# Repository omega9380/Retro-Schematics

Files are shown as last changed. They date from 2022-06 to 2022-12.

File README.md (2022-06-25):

# Retro Schematics
 Recreating retro computer schematics in KiCAD

I'm an IT administrator that likes to play around in KiCAD.  Needing a new project to keep me busy during downtime at work, I have decided to try my hand at recreating classic computer schematics.

Most retro schematics I have seen are scans from original system manuals.  While there are other folks that have recreated those schematics in various schematic CAD softwares like Eagle, Altium, or KiCAD, this is just fun for me.  It allows me to get to know KiCAD and all of its quirks and with this project I'll be able to help out the retro community.

My goal is to recreate the computer schematics as closely as the original diagrams that I find. I just think it will be helpful for all the retro folks out there to have an easy to reference schematic with some interactivity in a free-to-use software.

I will come straight to the point and say I suck at board design, but have become pretty good at symbol and schematic creation in KiCAD.  The goal of this repo is to provide the commuity a one-stop shop for schmatics for fixing thier old retro PCs.  And anyone can clone the repos and use the schematics to make thier own board designs (ATX format Commodore 64, anyone), or use these parts libraries to create addons that help the whole community enjoy thier classic computers and peripherals.

PDF versions of all schematics will be placed under "PDF Schematics" for those who don't want to install KiCAD.  The KiCAD projects will be under thier folders, seperated by company and device.

Note please that I am one guy, doing this on my own time.  So please don't expect that "one stop shop" to be available tomorrow!

If you like what I'm doing and want to help out, please branch and add to the repo if you have the skill, time, and inclination!

And if you want to help me out more directly, you can buy me a root beer:  

Any questions, comments, praises, worship, threats, or random thoughts, please DM me on Discord, I'm OmegaPrime#3078.

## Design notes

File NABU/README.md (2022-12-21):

# NABU
These are the schematics for the NABU PC, a Z80 based 8-bit computer.  The NABU PC was created in 1983 and was used to connect to the NABU Network, a cable-TV based early precursor to the World Wide Web that was available in Ottowa, Canada from 1982 to 1985.

A large number of the NABU PCs were recently posted on Ebay and the NABU hardware has become quite popular in the retro computing community.

The source document for this schematic replica is the "NABU Consolidated Documentation v1.0a" PDF.  This is a document compiled by user starkscon on Github, containing all the documentation he was able to find while exploring is own NABU.

## Notes on the schematic
- For whatever reason, the original schematic contains no part designators for any passives.  The only designators are for the ICs and I will label them thusly in the schematic.

## Links
- Check out starkscon on Github - [https://github.com/starkscon/nabu-z80](https://github.com/starkscon/nabu-z80)
- Adrian's Digital Basement video exploring the NABU - [https://www.youtube.com/watch?v=HLYjZoShjy0](https://www.youtube.com/watch?v=HLYjZoShjy0)

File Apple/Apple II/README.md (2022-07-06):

# Apple II

Source is the book *The Apple II Circuit Description* by Winston Gayler.

The schematics are in sections as opposed to a monolithic single schematic, so this looks like where we partake of the KiCAD heirarchal schematic system.

Hope you find this useful!

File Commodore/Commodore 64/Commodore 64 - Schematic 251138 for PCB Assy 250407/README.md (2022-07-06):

# Commodore 64

As we all know, there are multiple revisions of the C64 schematics.  My original plan was a top sheet, with the various versions of the schematic as sub-sheets, utilizing KiCAD's hierarchal sheet managament.  I quickly realized that this wouldn't really work, and it would make the C64 section of the repo HUGE once I was done.  I have since decided to seperate each version into its own project, based on the C64 Board Identification table on Page 17 of the Mar 1992 Service Manual (314001-03).

I will do my best to specify as much information as I can to match a schematic to a specific board, but there are so many out there that I may miss something.  Please put an issue in GitHub to let me know if I missed anything!

Most of the images and documents under the Documents folder here were found on the [Zimmers website](http://www.zimmers.net/), or on [MyOldComputer.nl](https://myoldcomputer.nl).   Please follow the links to these sites for a much more comprehensive document repository for the Commodore 64!

## Note on the RF Modulator schematic:

Several components are unlabeled or have no value.  This is due to the poor quality scan of the schematic from the service manuals.  If anyone can fill in  the blanks, please open an issue and let me know!

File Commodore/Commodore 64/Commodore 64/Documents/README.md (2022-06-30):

# Commodore 64

As we all know, there are multiple revisions of the C64 schematics.  What I plan on doing is a "top sheet" in KiCAD, with the various revision schematics as sub sheets for this top sheet.  I will do my best to specify as much information as I can to match a schematic to a specific board, but there are so many out there that I may miss something.  Please put an issue in GitHub to let me know if I missed anything!

Most of the images and documents here were found on the [Zimmers website](http://www.zimmers.net/).  I have saved them to this Documents folder while I work on the schematic for the C64, but I will remove them when the schematic is complete.  Please follow the link to Zimmers to get these files in the future!

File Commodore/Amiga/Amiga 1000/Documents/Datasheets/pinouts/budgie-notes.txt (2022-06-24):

Budgie is a chip that serves as the main data path element in the 
A1200 system. It provides the interface between the 32-bit processor 
bus and the 32-bit chip memory bus, generates the RAS and CAS 
select signals from the RAS and CAS timing signals that Alice 
supports. It also provides a 16-bit bus buffer which can be used for 
either an expansion bus or in this case the PCMCIA port data buffer. It 
also includes some miscellaneous functions, notably processor clock 
generation and 28Mhz/Genlock clock multiplexing.
It is implemented as a CMOS ASIC in a 128 Pin SMT package.
AdvancedAmiga 1200 System   11
Internally, the data path element is similar to Bridgette or the bus 
buffer/bridge logic implemented on the A3000 system. Data can be 
routed to/from the 32-bit processor port to either half of the 32-bit chip 
memory bus. Data can be bridged from the low order half of the chip 
memory bus to the high order half to support 16-bit Amiga chip 
accesses. Data read from memory is latched to meet the processor 
data hold requirements. CAS select logic is used to prevent contention 
when bridging the two halves of the chip bus.

The spare 16-bit expansion port(used for PCMCIA duty in the A1200) 
provides a simple path to/from the 16-bit processor port. The direction 
is dependent on the X-NOR of R_W and _BGACK signals to support 
either expansion bus or several purpose buffer requirements.

The memory decoding takes the RAS and CAS timing signals 
provided by Alice and the multiplexed address bus and generates 
appropriate selection for 32-bit accesses. It also uses A1/A0 and 
SIZ1/SIZ0 on processor accesses to do the right decoding there.

It supports 2-banks of 32 bit memory with 9-bit addressing for a total of 
2M-bytes of chip memory. RAS selection is used for bank selection, 
CAS selection is used for byte write control and to avoid contention on 
bridged reads. Refrcsh is done with CAS before RAS and the logic 
must assert all RAS and CAS signals during refresh cycles.

The processor clock generation simply X-NORS the 7MHz and *CDAC 
clocks to generate a 14MHz processor clock. The 28MHz/Genlock 
clock multiplexor is a simple 2 input multiplexor. It has no connection 
with the rest of the logic and can be used for other functions if desired. 
The CCK/4 output is provided for the PAL color burst generation 
circuitry.

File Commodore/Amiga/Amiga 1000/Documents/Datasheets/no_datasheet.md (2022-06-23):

# Missing Datasheets:

|Chip|More Info  |
|--|--|
|U4C - 8361 AGNUS| [Wikipedia Page](https://en.wikipedia.org/wiki/MOS_Technology_Agnus) |
|U4E - 8364 PAULA| [amigawiki Page (German)](https://www.amigawiki.org/doku.php?id=de:parts:paula)

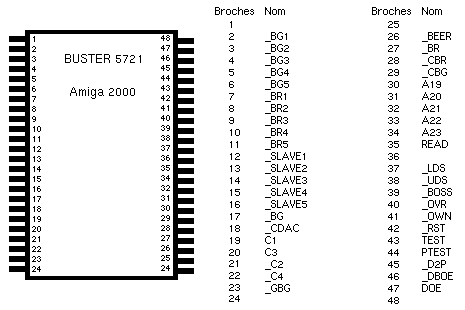
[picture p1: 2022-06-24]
Commodore/Amiga/Amiga 1000/Documents/Datasheets/pinouts/Buster.gif

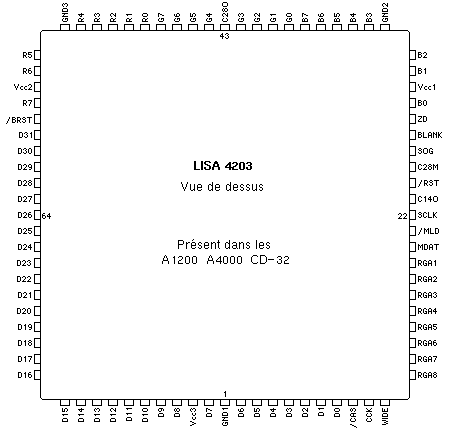
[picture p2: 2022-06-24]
Commodore/Amiga/Amiga 1000/Documents/Datasheets/pinouts/Lisa.gif

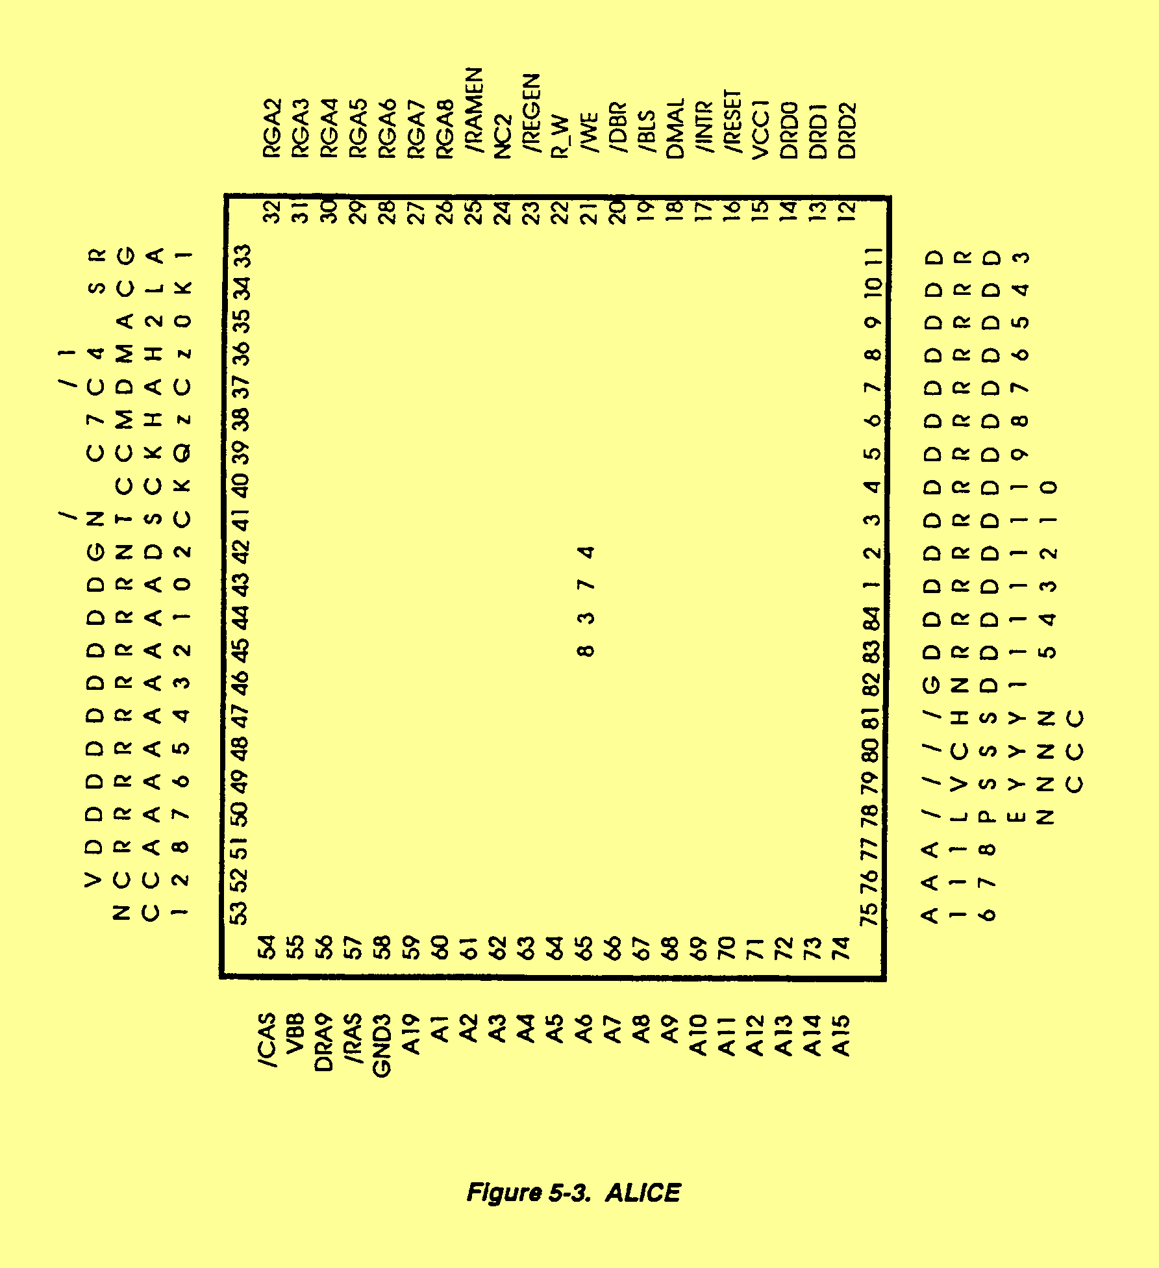
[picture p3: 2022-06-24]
Commodore/Amiga/Amiga 1000/Documents/Datasheets/pinouts/aa-alice.png

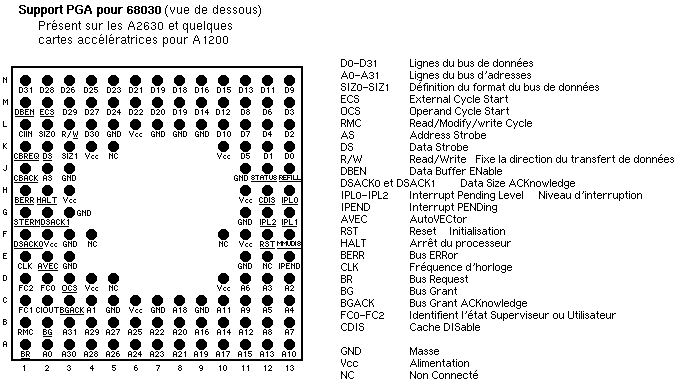
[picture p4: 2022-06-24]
Commodore/Amiga/Amiga 1000/Documents/Datasheets/pinouts/68030PGA.gif

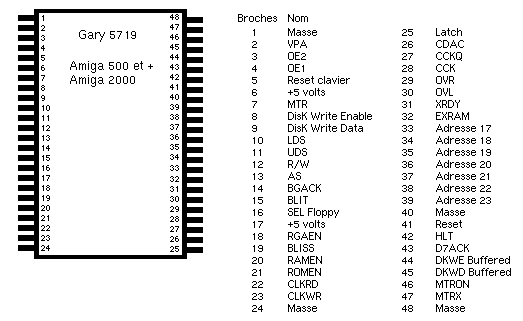
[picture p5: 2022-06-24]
Commodore/Amiga/Amiga 1000/Documents/Datasheets/pinouts/Gary.gif

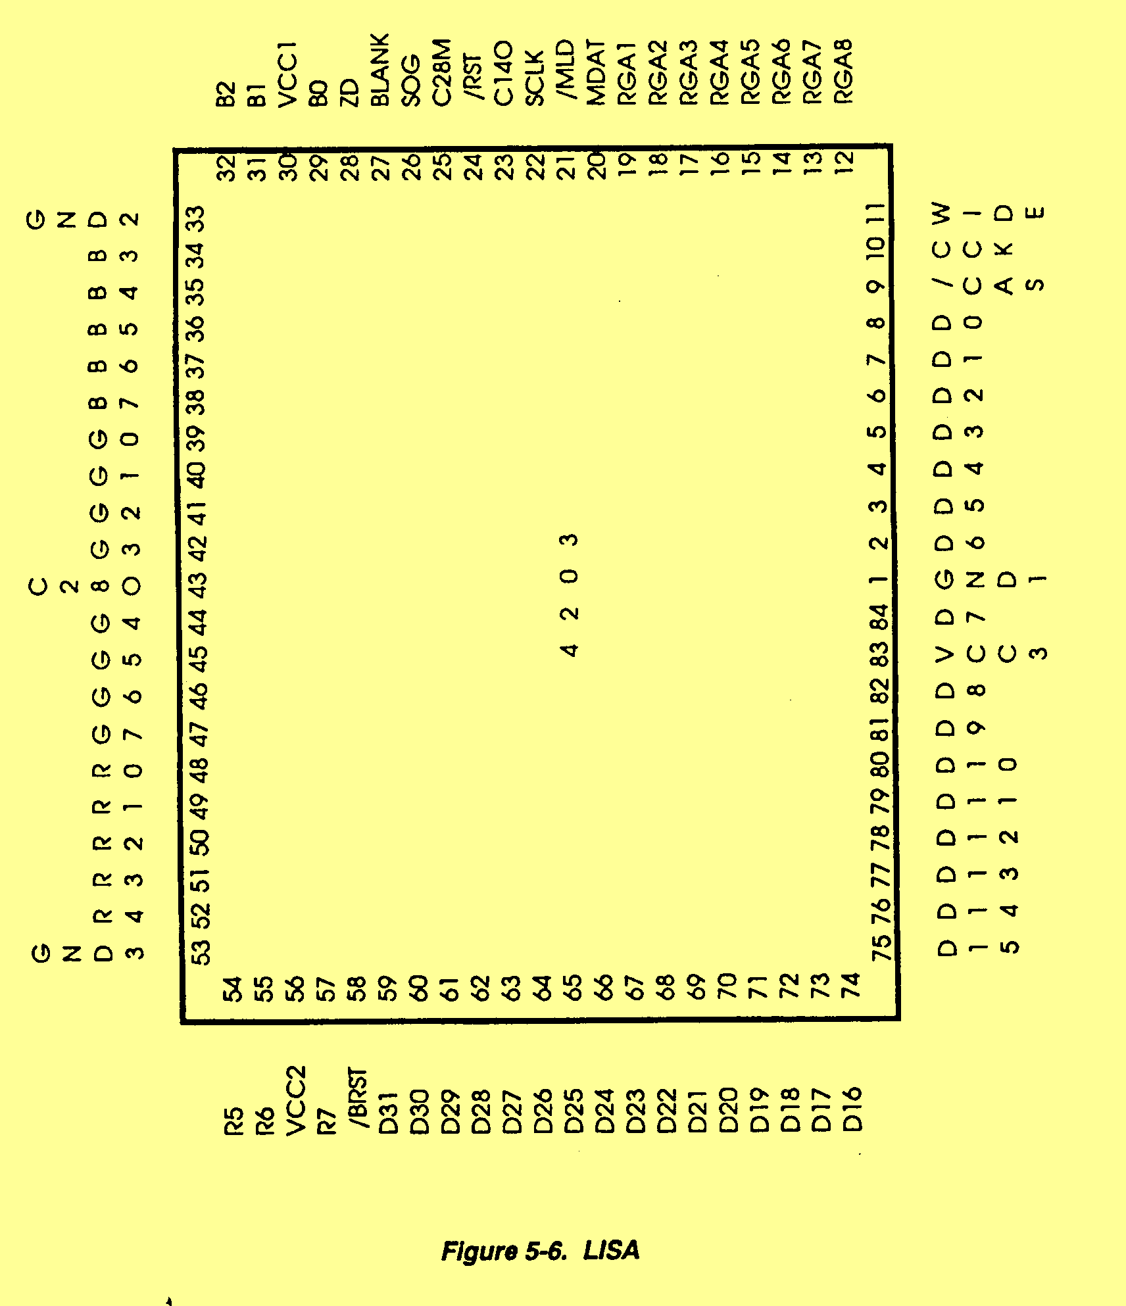
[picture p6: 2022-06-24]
Commodore/Amiga/Amiga 1000/Documents/Datasheets/pinouts/aa-lisa-plcc.png

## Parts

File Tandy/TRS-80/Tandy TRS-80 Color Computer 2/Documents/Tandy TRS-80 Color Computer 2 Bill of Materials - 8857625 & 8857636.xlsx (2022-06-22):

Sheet: Misc
ITEM | REF | DESCRIPTION | PART #
1 | 1 | PCB, MAIN LOGIC | 8709416
2 | 1 | LUG, FAST-ON | 8529016
3 | 9 | SOCKET, 16-PIN DIP (U1,14-21) | 8509003
4 | 3 | SOCKET, 20-PIN DIP (U3,5,6) | 8509009
5 | 2 | SOCKET, 24-PIN DIP (U12,13) | 8509001
6 | 5 | SOCKET, 40-PIN DIP (U2,7,8,22,23) | 8509002
7 | 1 | SWITCHCAP (RESET) | 8489066
8 | 1 | BRACKET, SWITCH (RESET) | 8729223
9 | 1 | HEATSINK, 6015-PBSE1 (Q1) | 8549016
10 | 2 | NUT, #6 KEPS | 8579004
11 | 1 | LABEL, PCB SERIAL | 8789963

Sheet: Capacitors (C)
REF | DESCRIPTION | PART #
C1 | 220µF, 16V, ELEC RAD | 8327221
C2 | 4700µF, 16V, ELEC RAD | 8328471
C3 | 0.1 µF, 50V, MONO AXIAL | 8374104
C4 | 0.1 µF, 50V, MONO AXIAL | 8374104
C5 | 100µF, 16V, ELEC RAD | 8327101
C6 | 0.1 µF, 50V, MONO AXIAL | 8374104
C7 | 0.02µF, 50V, CER DISK | 8303223
C8 | 0.02µF, 50V, CER DISK | 8303223
C9 | 0.02µF, 50V, CER DISK | 8303223
C10 | 0.02µF, 50V, CER DISK | 8303223
C11 | 100µF, 16V, ELEC RAD | 8327101
C12 | N.A.
C13 | 0.02µF, 50V, CER DISK | 8303223
C14 | 0.02µF, 50V, CER DISK | 8303223
C15 | 0.1 µF, 50V, MONO AXIAL | 8374104
C16 | 0.02µF, 50V, CER DISK | 8303223
C17 | 0.02µF, 50V, CER DISK | 8303223
C18 | 0.1 µF, 50V, MONO AXIAL | 8374104
C19 | 0.1 µF, 50V, MONO AXIAL | 8374104
C20 | 10µF, 25V, ELEC RD NP | 8396101
C21 | 0.1 µF, 50V, MONO AXIAL | 8374104
C22 | 0.02µF, 50V, CER DISK | 8303223
C23 | 0.02µF, 50V, CER DISK | 8303223
C24 | 0.1 µF, 50V, MONO AXIAL | 8374104
C25 | 0.1 µF, 50V, MONO AXIAL | 8374104
C26 | 0.001µF, 50V, POLY | 8352104
C27 | 0.02µF, 50V, CER DISK | 8303223
C28 | 0.1 µF, 50V, MONO AXIAL | 8374104
C29 | 0.1 µF, 50V, MONO AXIAL | 8374104
C30 | 0.1 µF, 50V, MONO AXIAL | 8374104
C31 | N.A.
C32 | 0.1 µF, 50V, MONO AXIAL | 8374104
C33 | 0.1 µF, 50V, MONO AXIAL | 8374104
C34 | 0.1 µF, 50V, MONO AXIAL | 8374104
C35 | 0.1 µF, 50V, MONO AXIAL | 8374104
C36 | 0.1 µF, 50V, MONO AXIAL | 8374104
C37 | 33pF, 50V, CER DISK | 8300334
C38 | 56pF, 50V, CER DISK | 8300564
C39 | 56pF, 50V, CER DISK | 8300564
C40 | 0.1 µF, 50V, MONO AXIAL | 8374104
C41 | N.A.
C42 | N.A.
C43 | 9-35pF TRIMMER | 8360356
C44 | 39pF, 50V, CER DISK | 8300394
C45 | 0.1 µF, 50V, MONO AXIAL | 8374104
C46 | 10µF, 25V, ELEC RAD | 8326102
C47 | 0.1 µF, 50V, MONO AXIAL | 8374104
C48 | 1µF, 50V, ELEC RAD | 8325104
C49 | N.A.
C50 | 0.1 µF, 50V, MONO AXIAL | 8374104
C51 | 0.1 µF, 50V, MONO AXIAL | 8374104
C52 | 0.1 µF, 50V, MONO AXIAL | 8374104
C53 | 0.1 µF, 50V, MONO AXIAL | 8374104
C54 | 0.1 µF, 50V, MONO AXIAL | 8374104
C55 | 0.1 µF, 50V, MONO AXIAL | 8374104
C56 | 0.1 µF, 50V, MONO AXIAL | 8374104
C57 | 0.1 µF, 50V, MONO AXIAL | 8374104
C58 | 0.1 µF, 50V, MONO AXIAL | 8374104
C59 | 150pF, 50V, CER DISK | 8301154
C60 | 33pF, 50V, CER DISK | 8300334
C61 | 150pF, 50V, CER DISK | 8301154
C62 | 10µF, 25V, ELEC RAD | 8326102

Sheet: Connectors (J)
REF | DESCRIPTION | PART #
J1 | 6-PIN DIN | 8519095
J2 | 6-PIN DIN | 8519095
J3 | 4-PIN DIN | 8519094
J4 | 5-PIN DIN | 8519085
J5 | KEYBOARD | 8519176
J6 | 40-PIN RIGHT ANGLE | 8519139

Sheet: Diodes (CR, FB, K)
REF | DESCRIPTION | PART #
CR1 | 1N4002, 50V, 1A | 8150002
CR2 | 1N4002, 50V, 1A | 8150002
CR3 | 1N5401, 100V, 3A | 8160401
CR4 | 1N5401, 100V, 3A | 8160401
CR5 | 1N4148 | 8150148
CR6 | 1N4148 | 8150148
CR7 | 1KF20-04 | 8160020
CR8 | 1KF20-04 | 8160020
CR9 | 1N4148 | 8150148
CR10 | 1N4148 | 8150148
CR11 | 1N4148 | 8150148
CR12 | 1N4148 | 8150148
CR13 | 1KF20-04 | 8160020
FB1 | FERRITE BEAD | 8419013
FB2 | FERRITE BEAD | 8419014
FB4 | FERRITE BEAD | 8419015
FB7 | FERRITE BEAD | 8419016
K1 | RELAY | 8429107

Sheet: Transistors (Q)
REF | DESCRIPTION | PART #
Q1 | SJ5812 | 8110569
Q2 | MPS3904 | 8110904

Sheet: Resistors (R, RP)
REF | DESCRIPTION | PART #
R1 | 51Ω, 1/4W 5% | 8207051
R2 | 0.1Ω, 1/2W 5% | 8247002
R3 | 270Ω, 1/4W 5% | 8207127
R4 | 510Ω, 1/4W 5% | 8207151
R5 | 4.7K, 1/4W 5% | 8207247
R6 | 4.7K, 1/4W 5% | 8207247
R7 | 10K, 1/4W 5% | 8207310
R8 | 10K, 1/4W 5% | 8207310
R9 | 1K, 1/4W 5% | 8207210
R10 | 9.1K, 1/4W 5% | 8207291
R11 | 100Ω, 1/2W 5% | 8217110
R12 | 4.7K, 1/4W 5% | 8207247
R13 | 10K, 1/4W 5% | 8207310
R14 | 4.7K, 1/4W 5% | 8207247
R15 | 1.5K, 1/4W 5% | 8207215
R16 | 10K, 1/4W 5% | 8207310
R17 | 4.7K, 1/4W 5% | 8207247
R18 | 4.7K, 1/4W 5% | 8207247
R19 | 100Ω, 1/4W 5% | 8207110
R20 | 100K, 1/4W 5% | 8207410
R21 | 4.7K, 1/4W 5% | 8207247
R22 | 100K, 1/4W 5% | 8207410
R23 | 220Ω, 1/2W 5% | 8217122
R24 | 100Ω, 1/4W 5% | 8207110
R25 | 150Ω, 1/4W 5% | 8207115
R26 | 100Ω, 1/4W 5% | 8207110
RP1 | RES PACK, 4.7K, 10 PIN | 8294247

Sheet: Switches (S)
REF | DESCRIPTION | PART #
S1 | DPDT, PUSH ON/OFF | 8489062
S2 | SPST, MOMENTARY | 8489065

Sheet: Integrated Circuits (U, Y)
REF | DESCRIPTION | PART #
U1 | CUSTOM SALT | 8050527
U2 | MC6821, PIA | 8040821
U3 | CUSTOM DAC | 8050526
U4 | NE555 | 8040055
U5 | 74LS273, OCTAL LATCH | 8020273
U6 | 74LS244, BUFFER | 8020244
U7 | MC6822, PIA | 8040822
U8 | MC6847, VDG | 8040847
U9 | RF MODULATOR | 8429500
U10 | 74LS02, QUAD NOR | 8020002
U11 | 74LS138, DECODER | 8020138
U12 | MC68A364, ROM | 8040364B
*U13 | MC68A364, ROM | 8040364A
U14 | MCM4517, RAM | 8040517
U15 | MCM4517, RAM | 8040517
U16 | MCM4517, RAM | 8040517
U17 | MCM4517, RAM | 8040517
U18 | MCM4517, RAM | 8040517
U19 | MCM4517, RAM | 8040517
U20 | MCM4517, RAM | 8040517
U21 | MCM4517, RAM | 8040517
U22 | MC6883, SAM | 8040278
U23 | MC6809E, CPU | 8040809
Y1 | CRYSTAL, 14.31818MHz | 8409008
* USED ON 8857636 EXTENDED BASIC PCB ONLY

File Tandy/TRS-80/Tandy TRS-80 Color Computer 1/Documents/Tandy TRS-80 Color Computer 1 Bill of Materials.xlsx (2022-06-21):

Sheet: Capacitors (C#)
SYMBOL | DESCRIPTION | MFG PART # | RS PART #
C1 | 1µF, 50V, electrolytic, radial | 8325104 | AAC105QJAP
C2 | 10µF, 25V, non-polarized, radial | 8396101 | AAC106QFBP
C3 | 100µF, 16V, electrolytic, radial | 8326251 | AAC107QDAP
C4 | 9 - 35 pF, variable | 8360356 | AC-4926
C5 | 100µF, 16V, electrolytic, radial | 8326251 | AAC107QDAP
C6 | 25µF, electrolytic, radial | 8326251 | AAC256MDAP
C7 | 1500µF, 35V, electrolytic, radial | 8318153 | AAC158QGAA
C8 | 100µF, 16V, electrolytic, radial | 8326251 | AAC107QDAP
C9 | 470µF, 35V, electrolytic, radial | 8327473 | AAC477QGAP
C10 | 10,000µF, 16V, electrolytic, axial | 8319101 | AAC109QDAA
C11 | 0.001µF, 50V, PO | 8352104 | AAC102KJGP
C12 | 100µF, 16V, electrolytic, radial | 8326251 | AAC107QDAP
C13 | 0.001µF, 50V, ceramic disc | 8302104 | AAC102QJCP
C14 | 220µF, 16V, electrolytic, radial | 8327221 | AAC227QDAP
C15 | 220µF, 16V, electrolytic, radial | 8327221 | AAC227QDAP
C16 | 220µF, 16V, electrolytic, radial | 8327221 | AAC227QDAP
C17 | 1µF, 50V, tantalum | 8335104 | AAC105QJTP
C18 | 1µF, 50V, tantalum | 8335104 | AAC105QJTP
C19 | 1µF, 50V, tantalum | 8335104 | AAC105QJTP
C20 | 0.01µF, 1KV, ceramic disc | 8303108 | AAC103QXCP
C21 | 0.01µF, 1KV, ceramic disc | 8303108 | AAC103QXCP
C22 | 0.01µF, 1KV, ceramic disc | 8303108 | AAC103QXCP
C23 | 0.1µF, 50V, monolithic,axial | 8374104 | AAC104QJCA
C24 | 0.1µF, 50V, monolithic,axial | 8374104 | AAC104QJCA
C25 | 0.1µF, 50V, monolithic,axial | 8374104 | AAC104QJCA
C26 | 0.022µF, 25V | 8303244 | AAC223QJCP
C27 | 0.1µF, 50V, monolithic,axial | 8374104 | AAC104QJCA
C28 | 0.1µF, 50V, monolithic,axial | 8374104 | AAC104QJCA
C29 | 0.1µF, 50V, monolithic,axial | 8374104 | AAC104QJCA
C30 | 0.022µF, 25V | 8303244 | AAC223QJCP
C31 | 0.1µF, 50V, monolithic,axial | 8374104 | AAC104QJCA
C32 | 0.1µF, 50V, monolithic,axial | 8374104 | AAC104QJCA
C33 | 0.1µF, 50V, monolithic,axial | 8374104 | AAC104QJCA
C34 | 0.1µF, 50V, monolithic,axial | 8374104 | AAC104QJCA
C35 | 0.1µF, 50V, monolithic,axial | 8374104 | AAC104QJCA
C36 | 0.1µF, 50V, monolithic,axial | 8374104 | AAC104QJCA
C37 | 0.1µF, 50V, monolithic,axial | 8374104 | AAC104QJCA
C38 | 0.1µF, 50V, monolithic,axial | 8374104 | AAC104QJCA
C39 | 0.1µF, 50V, monolithic,axial | 8374104 | AAC104QJCA
C40 | 0.1µF, 50V, monolithic,axial | 8374104 | AAC104QJCA
C41 | 0.1µF, 50V, monolithic,axial | 8374104 | AAC104QJCA
C42 | 0.1µF, 50V, monolithic,axial | 8374104 | AAC104QJCA
C43 | 0.1µF, 50V, monolithic,axial | 8374104 | AAC104QJCA
C44 | 0.1µF, 50V, monolithic,axial | 8374104 | AAC104QJCA
C45 | 0.1µF, 50V, monolithic,axial | 8374104 | AAC104QJCA
C46 | 0.1µF, 50V, monolithic,axial | 8374104 | AAC104QJCA
C47 | 0.1µF, 50V, monolithic,axial | 8374104 | AAC104QJCA
C48 | 0.1µF, 50V, monolithic,axial | 8374104 | AAC104QJCA
C49 | 0.1µF, 50V, monolithic,axial | 8374104 | AAC104QJCA
C50 | 0.1µF, 50V, monolithic,axial | 8374104 | AAC104QJCA
C51 | 39pF, ceramic disc | 8300394 | AAC390QJCP
C52 | 20pF, 50V, ceramic disc | 8300204 | AAC200QJCP
C53 | 56pF, 50V, ceramic disc | 8300564 | AAC560QJCP
C54 | 0.022µF, 25V | 8303244 | AAC223QJCP
C55 | 0.022µF, 25V | 8303244 | AAC223QJCP
C56 | 0.022µF, 25V | 8303244 | AAC223QJCP
C57 | 0.01µF, 50V, ceramic disc | 8303104 | AAC103QJCP
C58 | 0.01µF, 50V, ceramic disc | 8303104 | AAC103QJCP
C59 | 0.022µF, 25V | 8303244 | AAC223QJCP
C60 | 0.022µF, 25V | 8303244 | AAC223QJCP
C61 | 0.1µF, 50V, monolithic,axial | 8374104 | AAC104QJCA
C62 | 0.1µF, 50V, monolithic,axial | 8374104 | AAC104QJCA
C63 | 0.1µF, 50V, monolithic,axial | 8374104 | AAC104QJCA
C64 | 0.1µF, 50V, monolithic,axial | 8374104 | AAC104QJCA
C65 | 0.1µF, 50V, monolithic,axial | 8374104 | AAC104QJCA
C66 | 0.1µF, 50V, monolithic,axial | 8374104 | AAC104QJCA
C67 | 0.1µF, 50V, monolithic,axial | 8374104 | AAC104QJCA
C68 | 0.1µF, 50V, monolithic,axial | 8374104 | AAC104QJCA
C69 | 0.1µF, 50V, monolithic,axial | 8374104 | AAC104QJCA
C70 | 0.1µF, 50V, monolithic,axial | 8374104 | AAC104QJCA
C71 | 0.1µF, 50V, monolithic,axial | 8374104 | AAC104QJCA
C72 | 0.1µF, 50V, monolithic,axial | 8374104 | AAC104QJCA
C73 | 56pF, 50V, ceramic disc | 8300564 | AAC560QJCP
C74 | 0.022µF, 25V | 8303244 | AAC223QJCP
C75 | 56pF, 50V, ceramic disc | 8300564 | AAC560QJCP
C76 | 0.022µF, 25V | 8303244 | AAC223QJCP
C77 | 0.022µF, 25V | 8303244 | AAC223QJCP
C78 | 0.022µF, 25V | 8303244 | AAC223QJCP
C79 | 0.022µF, 25V | 8303244 | AAC223QJCP
C80 | 0.022µF, 25V | 8303244 | AAC223QJCP
C81 | 0.022µF, 25V | 8303244 | AAC223QJCP
C82 | 0.0022µF, 50V | 8302224 | AAC222MJCP
C83 | 0.001µF, 50V, ceramic disc | 8302104 | AAC102QJCP
C84 | 0.022µF, 25V | 8303244 | AAC223QJCP
C85 | 220pF, 50V, ceramic disc | 8301224 | AAC221QJCP

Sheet: Connectors (P#)
SYMBOL | DESCRIPTION | MFG PART # | RS PART #
P1 | 40 pin, AMP | 8519093 | AJ6902
P2 | 4 pin DIN | 8519094 | AJ6904
P3 | 6 pin DIN | 8519095 | AJ6905
P4 | 6 pin DIN | 8519095 | AJ6905
P5 | 5 pin DIN | 8519085 | AJ6903
*P6 | Keyboard shield connector | 8519104 | AJ6907
P7 | 16 pin Header | 8519106 | AJ6906
* will not appear on later revision Boards

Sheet: Crystals (X#)
SYMBOL | DESCRIPTION | MFG PART # | RS PART #
X1 | 14.31818MHz | 8409008 | AMX2797

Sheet: Diodes (CR#)
SYMBOL | DESCRIPTION | MFG PART # | RS PART #
CR1 | 1N4148 | 8150148 | ADX1152
CR2 | 1N4148 | 8150148 | ADX1152
CR3 | 1N4148 | 8150148 | ADX1152
CR4 | 1N4148 | 8150148 | ADX1152
CR5 | 1N4148 | 8150148 | ADX1152
CR6 | 1N4148 | 8150148 | ADX1152
CR7 | 1N4148 | 8150148 | ADX1152
CR8 | 1N4002 | 8150002 | ADX1148
CR9 | 1N982, zener | 8150982 | ADX1103
CR10 | 1N982, zener | 8150982 | ADX1103
CR11 | VM-28, bridge rectifier | 8160028 | AMX4582
CR12 | 1N5401, 100V, 3A | 8160401 | ADX1474
CR13 | 1N5401, 100V, 3A | 8160401 | ADX1474
CR14 | 1N4002 | 8150002 | ADX1148
CR15 | 1N4002 | 8150002 | ADX1148
CR16 | 1N5228, 3.9V, zener | 8150228 | ADX1473
CR17 | 1N4735, 6.2V, zener | 8150735 | ADX0214

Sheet: Fuses (F#)
SYMBOL | DESCRIPTION | MFG PART # | RS PART #
F1 | 700mA (0.7A) | 8479003 | AHF1185

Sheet: Inductors (L#)
SYMBOL | DESCRIPTION | MFG PART # | RS PART #
L1 | 3.3µh | 8419005 | ACA8059
L2 | 3.3µh | 8419005 | ACA8059
L3 | 3.3µh | 8419005 | ACA8059

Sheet: Integrated Circuits (U#)
SYMBOL | DESCRIPTION | MFG PART # | RS PART #
U1 | MC6809E, CPU | 8040809 | AXX3051
U2 | MC14050B, Latch | 8030050 | AMX4584
^U3 | MCM68A364, BASIC ROM | 8040364 | AXX3052
U4 | MC6821, PIA | 8040821 | AMX4578
U5 | UM1285-8, Modulator | 8050285 | AMX4576
U6 | 74LS273, Ocatal Flip-Flop | 8020273 | AMX4227
U7 | MC6847, VDG | 8040847 | AMX4575
U8 | MC6821, PIA | 8040821 | AMX4578
U9 | MC14529B, Data Separator | 8030529 | AMX4585
U10 | MC6883L, SAM | 8040278 | AMX4579
U11 | 74LS138, Decoder | 8020138 | AMX4583
U12 | MC1372, Video Mixer | 8020372 | AMX4574
U13 | 723C, +5V, Regulator | 8050723 | AMX3548
U14 | LM339, Quad Comparator | 8050339 | AMX4200
U15 | 741C, OpAmp | 8050741 | AMX4258
U16 | 74LS244, Buffer | 8020244 | AMX3864
U17 | 78M12, +12V, Regulator | 8050812 | AMX4577
U18 | 79M12, -12V, Regulator | 8050912 | AMX1488
U19 | 79L05, -5V Regulator | 8051905 | AMX4260
*U20 | MCM4027AC3, 4K RAM | 8040027 | AXX3044
*U21 | MCM4027AC3, 4K RAM | 8040027 | AXX3044
*U22 | MCM4027AC3, 4K RAM | 8040027 | AXX3044
*U23 | MCM4027AC3, 4K RAM | 8040027 | AXX3044
*U24 | MCM4027AC3, 4K RAM | 8040027 | AXX3044
*U25 | MCM4027AC3, 4K RAM | 8040027 | AXX3044
*U26 | MCM4027AC3, 4K RAM | 8040027 | AXX3044
*U27 | MCM4027AC3, 4K RAM | 8040027 | AXX3044
†U28 | MCM68A364, BASIC ROM Extended | 8042364 | AXX3054
U29 | 74LS02, Quad NOR Gate | 8020002 | AMX3551
^ Handwritten note: SCM90590C; 8040364A; Rev 1.18112.
* For 16K RAM Model
U20 - U27 | SCM90072C, 16K RAM | 8040016 | AXX3055
† For 16K RAM version only

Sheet: Relays (K#)
SYMBOL | DESCRIPTION | MFG PART # | RS PART #
K1 | R7336-1 | 8429102 | AR8130

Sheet: Resistors (R#)
SYMBOL | DESCRIPTION | MFG PART # | RS PART #
R1 | 100K, 1/4W, 5% | 8207410 | AN0371EEC
R2 | 100K, 1/4W, 5% | 8207410 | AN0371EEC
R3 | 4.7K, 1/4W, 5% | 8207247 | AN0247EEC
R4 | 4.7K, 1/4W, 5% | 8207247 | AN0247EEC
R5 | 4.7K, 1/4W, 5% | 8207247 | AN0247EEC
R6 | 4.7K, 1/4W, 5% | 8207247 | AN0247EEC
R7 | 4.7K, 1/4W, 5% | 8207247 | AN0247EEC
R8 | 18K, 1/4W, 5% | 8207318 | AN0303EEC
R9 | 150 ohm, 1/4W, 5% | 8207115 | AN0142EEC
R10 | 10K, 1/4W, 1% | 8201310 | AN0281BEE
R11 | 20K, 1/4W, 1% | 8201320 | AN0306BEE
R12 | 40.2K, 1/4W, 1% | 8201340 | AN0597BEE
R13 | 80.6K, 1/4W, 1% | 8201381 | AN0359BEE
R14 | 162K, 1/4W, 1% | 8201416 | AN0385BEE
R15 | 324K, 1/4W, 1% | 8201432 | AN0408BEE
R16 | 3.9K, 1/4W, 5% | 8207239 | AN0237EEC
R17 | 470 ohm, 1/4W, 5% | 8207147 | AN0169EEC
R18 | 750 ohm, 1/4W, 5% | 8207175 | AN0185EEC
R19 | 12K, 1/4W, 5% | 8207312 | AN0288EEC
R20 | 360 ohm, 1/4W, 5% | 8207136 | AN0159EEC
R21 | 500 ohm, Trim Pot | 8279150 | AP7156
R22 | 10K, 1/4W, 5% | 8207310 | AN0281EEC
R23 | 3.9K, 1/4W, 5% | 8207239 | AN0237EEC
R24 | 1.5K, 1/4W, 5% | 8207215 | AN0206EEC
R25 | 1K, 1/4W, 5% | 8207210 | AN0196EEC
R26 | 1K, 1/4W, 5% | 8207210 | AN0196EEC
R27 | 100 ohm, 1/2W, 5% | 8217110 | AN0132EFB
R28 | 10K, 1/4W, 5% | 8207310 | AN0281EEC
R29 | 10K, 1/4W, 5% | 8207310 | AN0281EEC
R30 | 1K, 1/4W, 5% | 8207210 | AN0196EEC
R31 | 4.7K, 1/4W, 5% | 8207247 | AN0247EEC
R32 | 4.7K, 1/4W, 5% | 8207247 | AN0247EEC
R33 | 220 ohm, 1/4W, 5% | 8207122 | AN0149EEC
R34 | 8.2K, 1/4W, 5% | 8207282 | AN0271EEC
R35 | 6.8K, 1/4W, 5% | 8207268 | AN0262EEC
R36 | 56K, 1/4W, 5% | 8207356 | AN0345EEC
R37 | 56K, 1/4W, 5% | 8207356 | AN0345EEC
R38 | 15K, 1/4W, 5% | 8207315 | AN0297EEC
R39 | 1.5M, 1/4W, 5% | 8207515 | AN0450EEC
R40 | 1K, 1/4W, 5% | 8207210 | AN0196EEC
R41 | 24K, 1/4W, 5% | 8207324 | AN0526EEC
R42 | 75K, 1/4W, 5% | 8207375 | AN0527EEC
R43 | 1.5K, 1/4W, 5% | 8207215 | AN0206EEC
R44 | 4.7K, 1/4W, 5% | 8207247 | AN0247EEC
R45 | 180 ohm, 1/4W, 5% | 8207118 | AN0144EEC
R46 | 470 ohm, 1/4W, 5% | 8207147 | AN0169EEC
R47 | 1.5K, 1/4W, 5% | 8207215 | AN0206EEC
R48 | 10K, 1/4W, 5% | 8207310 | AN0281EEC
R49 | 10M, 1/4W, 5% | 8207610 | AN0482EEC
R50 | 100 ohm, 1/2W, 5% | 8217110 | AN0132EFB
R51 | 10K, 1/4W, 5% | 8207310 | AN0281EEC
R52 | 10K, 1/4W, 5% | 8207311 | AN0281EEC
R53 | 15K, 1/4W, 5% | 8207315 | AN0297EEC
R54 | 15K, 1/4W, 5% | 8207315 | AN0297EEC
R55 | 10M, 1/4W, 5% | 8207610 | AN0482EEC
R56 | 10M, 1/4W, 5% | 8207610 | AN0482EEC
R57 | 1K, 1/4W, 5% | 8207210 | AN0196EEC
R58 | 470 ohm, 1/4W, 5% | 8207147 | AN0169EEC
R59 | 68 ohm, 1/4W, 5% | 8207068 | AN0111EEC
R60 | 1K, Trim Pot | 8279210 | AP0835
R61 | 1.2K, 1/4W, 5% | 8207212 | AN0199EEC
R62 | 3.3K, 1/4W, 5% | 8207233 | AN0230EEC
R63 | 1.2K, 1/4W, 5% | 8207212 | AN0199EEC
R64 | 4.7K, 1/4W, 5% | 8207247 | AN0247EEC
R65 | 560 ohm, 1/4W, 5% | 8207156 | AN0176EEC
R66 | 0.33 ohm, 2W | 8247833 | AN0522EHB
R67 | 1.2K, 1/4W, 5% | 8207212 | AN0199EEC
R68 | 10K, 1/4W, 5% | 8207310 | AN0281EEC
R69 | 820 ohm, 1/4W, 5% | 8207182 | AN0187EEC
R70 | not used
R71 | 220 ohm, 1/4W, 5% | 8207122 | AN0149EEC
R72 | 100K, 1/4W, 5% | 8207410 | AN0371EEC
*R73 | 470 ohm, 1/4W, 5% | 8207147 | AN0169EEC
*R74 | 470 ohm, 1/4W, 5% | 8207147 | AN0169EEC
†R75 | 33 ohm, resistor pak | 8290014 | ARX0220
†R76 | 33 ohm, 1/4W, 5% | 8207033 | AN0087EEC
†R77 | 33 ohm, 1/4W, 5% | 8207033 | AN0087EEC
R78 | 33 ohm, 1/4W, 5% | 8207033 | AN0087EEC
R79 | 33 ohm, 1/4W, 5% | 8207033 | AN0087EEC
R80 | 470 ohm, 1/4W, 5% | 8207147 | AN0169EEC
* May appear as follows:
 | Ferrite Bead, #2643021801 | 8419012 | ---------
† May appear as follows:
 | Ferrite Bead, #264000301 | 8419014 | ---------

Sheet: Switches (S#)
SYMBOL | DESCRIPTION | MFG PART # | RS PART #
S1 | Reset | 8110904 | S0852
S2 | Power, 4PDT | 8489002 | S0851
S3 | Channel Select, SPST | 8489029 | S9142

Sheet: Transformers (T#)
SYMBOL | DESCRIPTION | MFG PART # | RS PART #
T1 | 33.5V and 16.3V, 50-60Hz | 8790020 | ATA0856

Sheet: Transistors (Q#)
SYMBOL | DESCRIPTION | MFG PART # | RS PART #
Q1 | MPS3904 | 8110904 | AMX3583
Q2 | 2N6594, PNP | 8100594 | AMX3798
Q3 | TIP29, NPN | 8110029 | AMX3582
Q4 | 2N2222 | 8110222 | AMX4263

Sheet: Miscellanous
DESCRIPTION | QUANTITY | MFG PART # | RS PART #
Cartridge Slide Guide | 1 | 8719110 | ART3326
Clip, Fuse | 2 | 8479004 | AF1176
Ground Plane Bottom | 1 | 8729043 | AHD3325
Ground Plane Fastener | 16 | 8559023 | AHD9012
Ground Plane Insulator | 1 | 8539008 | ART3324
Insulator, mica | 1 | 8539009 | AHC0322
Jumper Cable, transfomerer | 1 | 8709158 | AW2586
Jumper Plug | 2 | 8519021 | AJ6769
Socket, 16 pin | 8 | 8509003 | AJ6581
Socket, 24 pin | 2 | 8509001 | AJ6579
Socket, 40 pin | 4 | 8509002 | AJ6580
Tubing, air shrink, 3/4" | 3 | 8539011 | AHC0323

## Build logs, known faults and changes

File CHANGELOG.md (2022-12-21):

# CHANGELOG
### 16 Dec 2022
- Back at it after a long break!  Going to finish the PSU schematic page for the Apple II, which will finish the Apple II schematic altogether.

### 21 Dec 2022
- Finished the Apple II schematic (finally!).
- Due to the current popularity in the community, I'm going to do a schematic of the NABU computer next.

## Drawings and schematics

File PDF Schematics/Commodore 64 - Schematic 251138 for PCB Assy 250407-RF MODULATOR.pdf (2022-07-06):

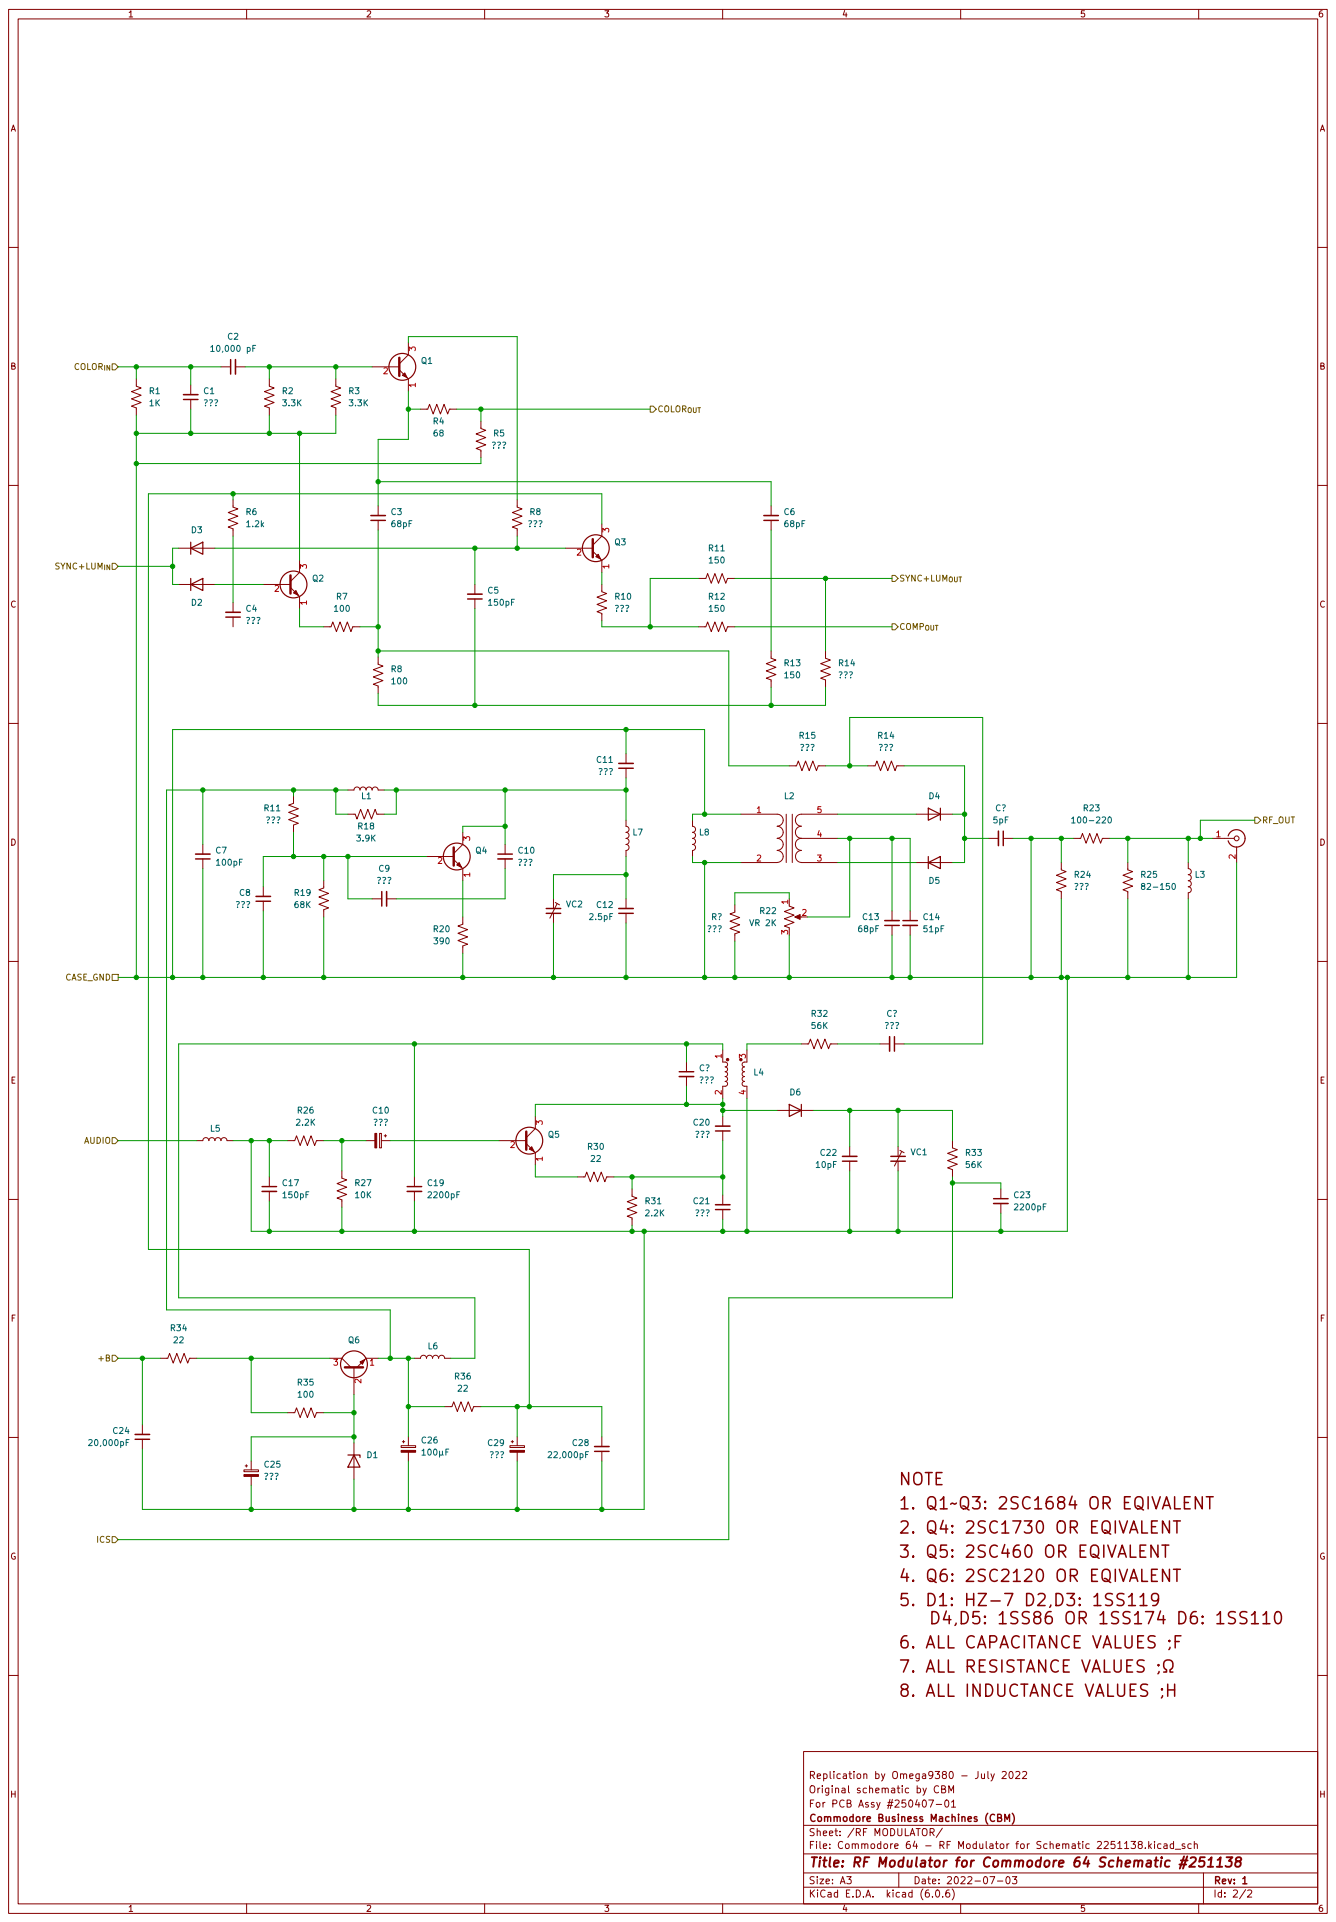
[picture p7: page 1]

Original schematic by CBM
For PCB Assy #250407-01
File: Commodore 64 - RF Modulator for Schematic 2251138.kicad_sch Sheet: /RF MODULATOR/ Commodore Business Machines (CBM)

Id: 2/2 Title: RF Modulator for Commodore 64 Schematic #251138

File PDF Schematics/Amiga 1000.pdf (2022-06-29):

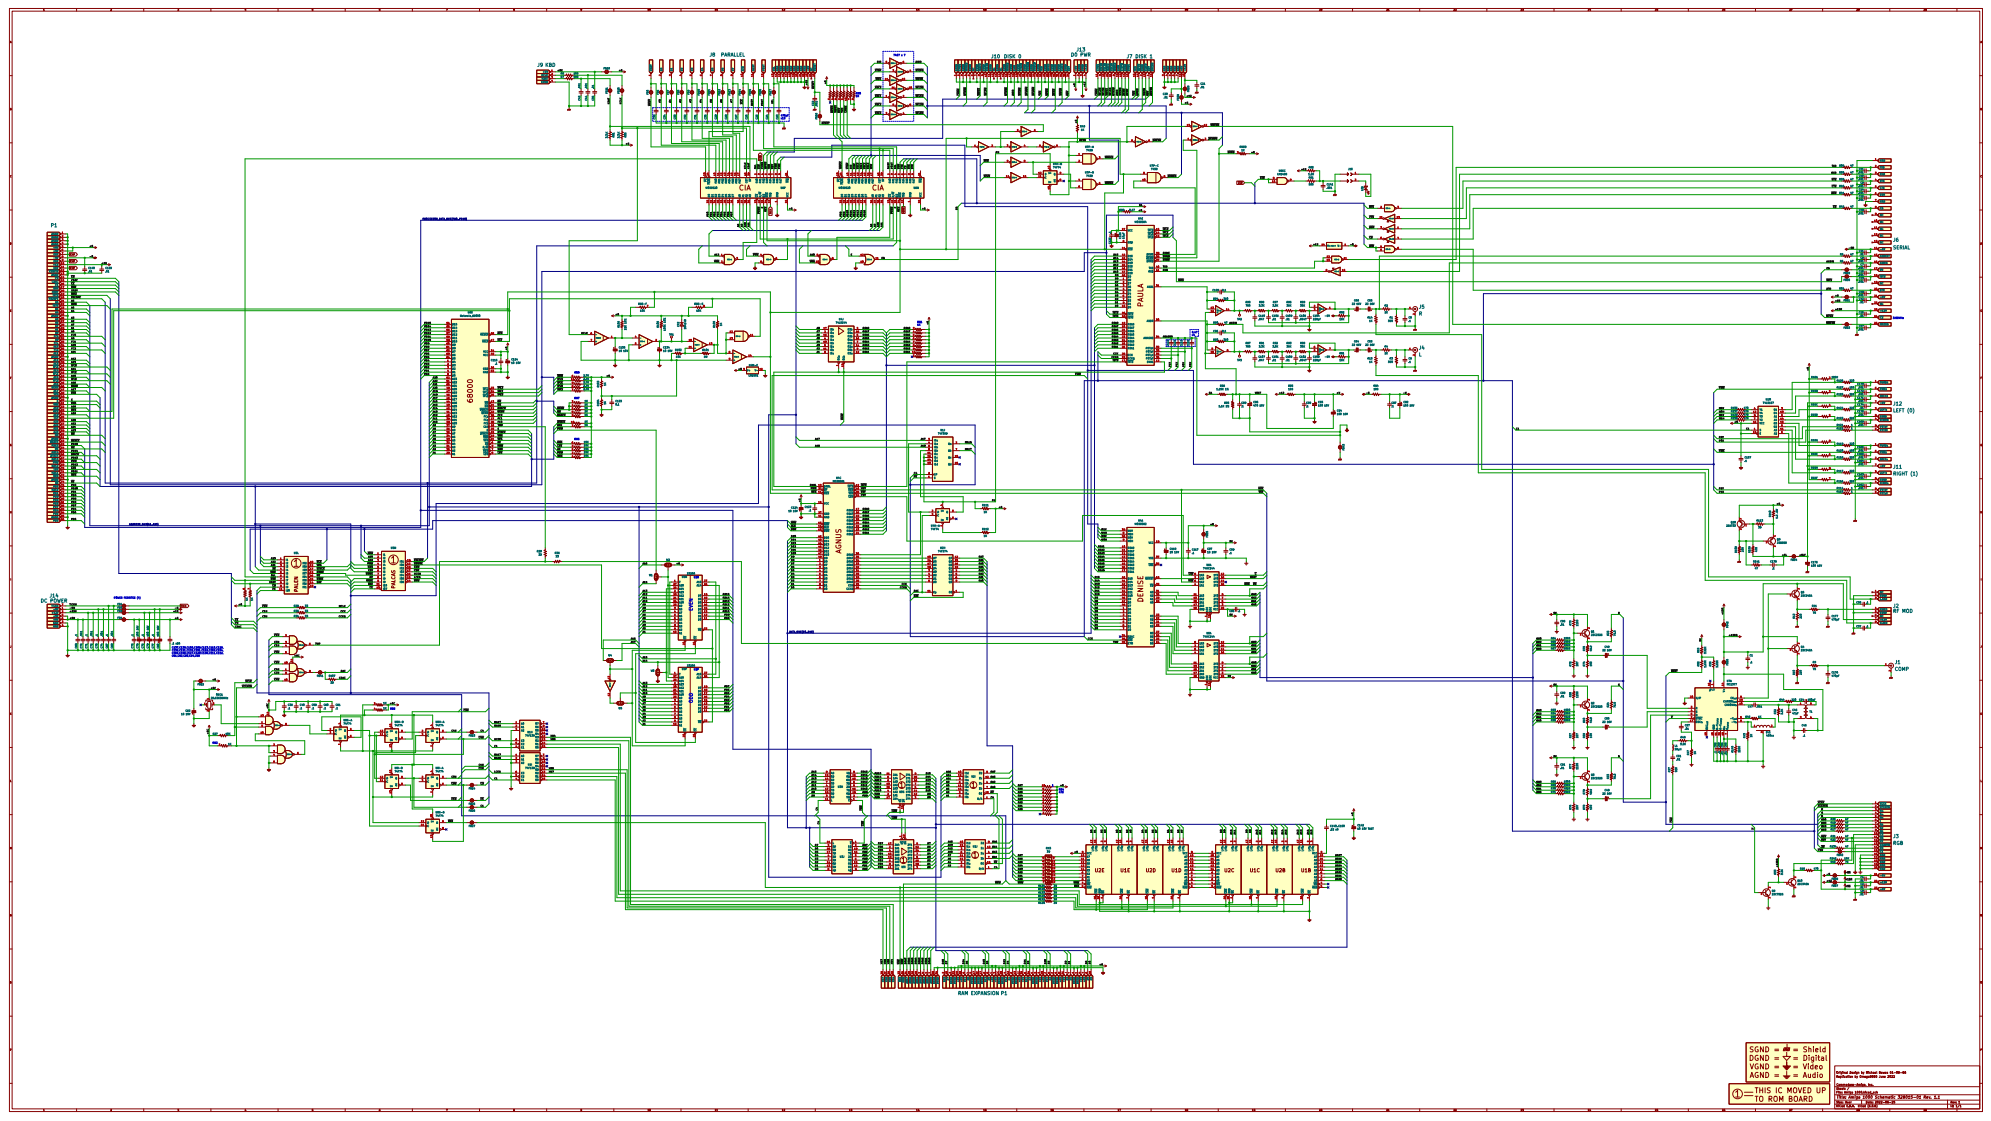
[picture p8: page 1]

~{BR} 60 DGND 61 ~{BGACK} 62 PD15 63 ~{BG} 64 PD14 65 ~{DTACK} 66 PD13 67 ~{PRW} 68 PD12 69

~{BGACK}
~{LDS} 70 PD11 71 ~{UDS} 72 DGND 73 ~{AS} 74 PD0 75 PD10 76 PD1 77 PD9 78

File: Amiga 1000.kicad_sch Sheet: / Commodore-Amiga, Inc.

Id: 1/1 Title: Amiga 1000 Schematic 328015-01 Rev. 1.1

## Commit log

2022-06-17 Create Tandy TRS-80 Color Computer 1 Bill of Materials.xlsx
    [Tandy TRS-80 Color Computer 1 Bill of Materials.xlsx]
2022-06-17 Copied over the RIGHT bill o' mat'ls because Microsoft are stupid :(
    [Tandy TRS-80 Color Computer 1 Bill of Materials.xlsx]
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2022-06-21 Forgot to annotate some caps, fixed!
    [Tandy TRS-80 Color Computer 1.kicad_sch]
2022-06-22 Rename parts to sort by device, fixed some missing annotations on CoCo1
    [Tandy TRS-80 Color Computer 1.kicad_sch, Tandy TRS-80 Color Computer 2.kicad_pcb, Tandy TRS-80 Color Computer 2.kicad_sch]
2022-06-22 Create Tandy TRS-80 Color Computer 2 Bill of Materials - 8857625 & 8857636.xlsx
    [Tandy TRS-80 Color Computer 2 Bill of Materials - 8857625 & 8857636.xlsx]
2022-06-22 Update Tandy TRS-80 Color Computer 2 Bill of Materials - 8857625 & 8857636.xlsx
    [Tandy TRS-80 Color Computer 2 Bill of Materials - 8857625 & 8857636.xlsx]
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2022-06-26 More work on the Amiga 1000 schematic
    I NEED A BREAK!
    [Amiga 1000.kicad_sch]
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2022-06-26 Even more Amiga schematic work
    Is it a problem if I'm seeing chips and wires in my DREAMS!??! :(
    [Amiga 1000.kicad_sch]
2022-06-27 You guessed it. Even more Amiga 1000 schematic work!
    If I ever meet Michael Bowes, I'm gonna slap him with a wet noodle.
    [Amiga 1000.kicad_sch]
2022-06-27 Surprise! More Amiga 1000 schematic work!
    I need a break..................
    [Amiga 1000.kicad_sch]
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2022-06-28 Even. More. Amiga 1000. Schematic. Work.
    I'm inching ever closer!!!!
    [Amiga 1000.kicad_sch]
2022-06-28 You know what I worked on!
    I'm ALMOST DONE!!!!! (with the Amiga 1000)
    [Amiga 1000.kicad_sch]
2022-06-29 Amiga 1000 schematic. COMPLETE!!
    Oh thank the MAKER!
    [Amiga 1000.kicad_sch]
2022-06-29 Forgot the 26 caps on the power input - Amiga 1000
    [Amiga 1000.kicad_sch]
2022-06-30 Began research work for Commodore 64
    Holy revisions, Batman!
    [Commodore 64.kicad_pcb, Commodore 64.kicad_sch]
2022-06-30 Fixed folder hierarchy for the C64 folder
    [Commodore 64.kicad_pcb, Commodore 64.kicad_sch]
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2022-07-01 Modified TRS80 CoCo 1 library from global to local and removed global library.
    [Tandy TRS-80 Color Computer 1.kicad_sch]
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2022-07-06 Missed a ground connection on U20B - C64 251138
    [Commodore 64 - Schematic 251138 for PCB Assy 250407.kicad_sch]
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2022-07-11 Several Apple II updates
    Finished parts libarary
    Created schematic cover sheet (Sheet 1)
    Created table of contents on sheet 1
    Finished Sheet 2 - Clock Generator
    [Apple II - Clock Generator (all revisions).kicad_sch, Apple II - Memory Address Pt 1 of 2 (Rev 0,1).kicad_sch, Apple II - Memory Address Pt 1 of 2 (Rev 7,RFI).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]
2022-07-12 Finished Apple II Sheet 3 of 23: Video Address Generator (all revisions)
    [Apple II - Clock Generator (all revisions).kicad_sch, Apple II - Memory Address Pt 1 of 2 (Rev 0,1).kicad_sch, Apple II - Memory Address Pt 1 of 2 (Rev 7,RFI).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]
2022-07-12 Completed Apple II - Memory Address Pt 1 of 2 (Rev 0,1)
    [Apple II - Clock Generator (all revisions).kicad_sch, Apple II - Memory Address Pt 1 of 2 (Rev 0,1).kicad_sch, Apple II.kicad_sch]
2022-07-12 Finished Apple II - Sheet 5 - Memory Address Pt 1 of 2 (Rev 7,RFI)
    [Apple II - Clock Generator (all revisions).kicad_sch, Apple II - Memory Address Pt 1 of 2 (Rev 0,1).kicad_sch, Apple II - Memory Address Pt 1 of 2 (Rev 7,RFI).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]
2022-07-12 Finished Apple II - Sheet 6 - Memory Address Pt 2 of 2 (All Revisions)
    [Apple II - Clock Generator (all revisions).kicad_sch, Apple II - Memory Address Pt 1 of 2 (Rev 0,1).kicad_sch, Apple II - Memory Address Pt 1 of 2 (Rev 7,RFI).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]
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2022-07-13 Fixed some missing notes on Apple II - Sheet 11 - Peripheral I/O (all revisions)
    [Apple II - Peripheral IO (All Revisions).kicad_sch, Apple II.kicad_sch]
2022-07-13 Finished Apple II - Sheet 12 - On-Board I/O Pt 1 of 2 (all revisions)
    [Apple II - On-board IO Pt 1 of 2 (All Revisions).kicad_sch, Apple II - Peripheral IO (All Revisions).kicad_sch, Apple II.kicad_sch]
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2022-07-14 Finished Apple II - Sheet 14 - Video Generator Part 1 (Rev 0)
    [Apple II - Clock Generator (all revisions).kicad_sch, Apple II - Memory Address Pt 1 of 2 (Rev 0,1).kicad_sch, Apple II - Memory Address Pt 1 of 2 (Rev 7,RFI).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]
2022-07-14 Finished Apple II - Sheet 15 - Video Generator Part 1 (Rev 1)
    [Apple II - Video Generator Pt 1 of 2 (Rev 0).kicad_sch, Apple II - Video Generator Pt 1 of 2 (Rev 1).kicad_sch, Apple II.kicad_sch]
2022-07-14 Finished Apple II - Sheet 16 - Video Generator Part 1 (Rev 7, RFI)
    [Apple II - Clock Generator (all revisions).kicad_sch, Apple II - RAM (All Revisions).kicad_sch, Apple II - Video Generator Pt 1 of 2 (Rev 0).kicad_sch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]
2022-07-14 Finished Apple II - Sheet 17 - Video Generator Part 2 (Rev 0)
    [Apple II - Video Generator Pt 2 of 2 (Rev 0).kicad_sch, Apple II.kicad_sch]
2022-07-14 Finished Apple II - Sheet 18 - Video Generator Part 2 (Rev 1)
    [Apple II - Video Generator Pt 2 of 2 (Rev 0).kicad_sch, Apple II - Video Generator Pt 2 of 2 (Rev 1).kicad_sch, Apple II.kicad_sch]
2022-07-14 Finished Apple II - Sheet 19 - Video Generator Part 2 (Rev 7)
    [Apple II - Video Generator Pt 2 of 2 (Rev 1).kicad_sch, Apple II - Video Generator Pt 2 of 2 (Rev 7).kicad_sch, Apple II.kicad_sch]
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2022-07-15 Finished Apple II - Sheet 20 - Video Generator Part 2 (Rev RFI)
    [Apple II - Clock Generator (all revisions).kicad_sch, Apple II - Memory Address Pt 1 of 2 (Rev 0,1).kicad_sch, Apple II - Memory Address Pt 1 of 2 (Rev 7,RFI).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]
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2022-07-17 Working on Apple II - Sheet 23
    My eyes said I need a break :smile:
    [Apple II - Power Supply.kicad_sch, Apple II - Two-piece Keyboard.kicad_sch, Apple II.kicad_sch]
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2023-12-01 Didn't do nuttin, too tired
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
